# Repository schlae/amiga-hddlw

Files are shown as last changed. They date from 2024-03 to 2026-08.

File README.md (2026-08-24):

# Herr Doktor Diskettenlaufwerk (Amiga-HDDLW)

Late-model Amiga computers use customized floppy drives (like the Chinon
FZ-357A) to be able to read and write high-density floppy disks
(colloquially known as 1.44MB floppies, although the Amiga can store 1.76MB
because it packs in four additional sectors per track.)

Why a customized floppy drive? The Amiga custom chip, Paula, only supports
the slower bit rate used by double-density floppy disks. Instead of spending
a bunch of money to change the Paula chip, Commodore engineers got a
customized floppy drive that spun the disk at half speed when it detected
a high-density floppy disk.

In the 1990s, some 3rd party vendors released Amiga compatible floppy drives.
One such design is the AMTRADE "The Real HD-Drive" A357. It uses a modified
Sony MPF920-E or a TEAC FD-235HF (both fairly common) along with a small
adapter circuit board containing a 16V8 PAL.

I've done a bit of reverse engineering to understand how the A357 works,
and I've been able to build a functional replica. It's not an exact copy
because the original PAL is locked. I'm calling it the Herr Doktor
Diskettenlaufwerk, or HDDLW.

*Please note that I have not fabbed out this design yet, and although the
design is tested and expected to work, go forward at your own risk.*

## Fabrication

The board is a simple 2-layer affair with a small handful of parts. The
dimensions are 93.5mm x 20.3mm (3.68" x 0.8").

[Schematic](https://github.com/schlae/amiga-hddlw/blob/main/amiga-hddlw.pdf)

[Bill of Materials](https://github.com/schlae/amiga-hddlw/blob/main/amiga-hddlw.csv)

[Fab Package](https://github.com/schlae/amiga-hddlw/blob/main/fab/amiga-hddlw_rev1.zip)

Install a 20-pin DIP socket in position U1 just in case you have trouble
programming the PAL. All parts, with the exception of J2, J5, and J6, should
be installed on the top side of the board.

J4 should be a Molex 4-pin header with a key. In a pinch, you can sub it out
with a standard 4-pin header but it will be very easy to connect the cable
backwards, which will put 12V on the drive's 5V rail, destroying everything!

Install **either** J5 **or** J6 depending on the drive you plan to use. If you
install both, J5 will interfere with the drive select jumpers on the Sony
drive and potentially damage them.

Jumper J3 should be set to 1 for DF0 and 2 for DF1. Position 3 has not been
tested yet but may work.

## Rework

You will (most likely) need to add a bodge resistor to the design for it to
operate properly on many drives. This is because the pullup on the INDEX line
on the drive itself is weak or nonexistent. Connect a 10K ohm resistor from
pin 7 of the PAL to pin 20 of the PAL.

(Bottom view of the board)
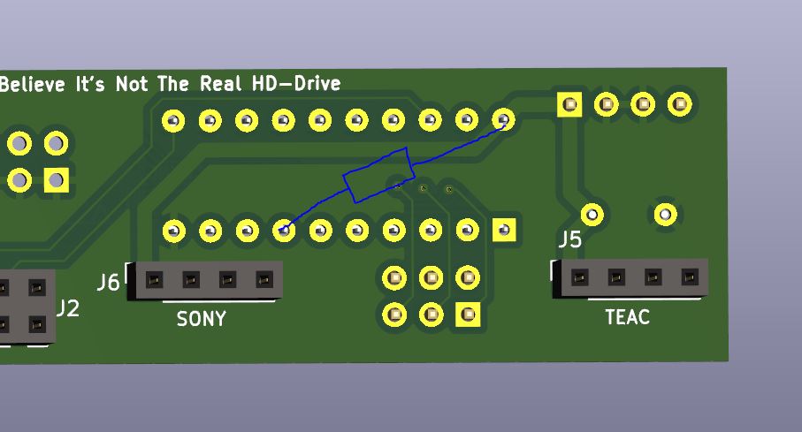
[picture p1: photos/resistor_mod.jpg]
Reverse view of the board showing resistor


## PAL programming

See the [source file](https://github.com/schlae/amiga-hddlw/blob/main/pal/amiga-hddlw.pld).

The logic equations are assembled using [galette](https://github.com/simon-frankau/galette)
and can be burned to the PAL using a number of different tools. I use the
TL-866 with the [minipro](https://gitlab.com/DavidGriffith/minipro) tool under
Linux, along with the ATF16V8B. The speed grade is not critical.

## Drive modifications

The HDDLW has been tested with the two floppy drives below. It may be possible
to use it with other drives, but you will need to investigate to figure out
the clock connection that sets the motor RPM. You will also need to figure
out how to get the high density select signal onto pin 4 of the drive.

### Sony MPF920-E

Perform the following changes

* Install JC40 (a zero ohm resistor or wire jumper), which is connected to pin
4 of the floppy connector and provides the high-density sense signal. See the
green circle in the image below.
* Cut the trace between pin 38 of IC1 and pin 16 of IC2. This is the motor
driver clock. This is indicated by the diagonal arrow in the image below.
* Connect a wire from pin 38 of IC1 to pin 14 of the floppy connector (blue
wire in the image)
* Connect a wire from pin 16 of IC2 to pin 6 of the floppy connector (red
wire in the image)
* (Optional) This drive *may* have issues regulating the motor speed at lower RPMs. You can try changing resistor R21 (located next to IC2) from 100K to a 68K resistor.

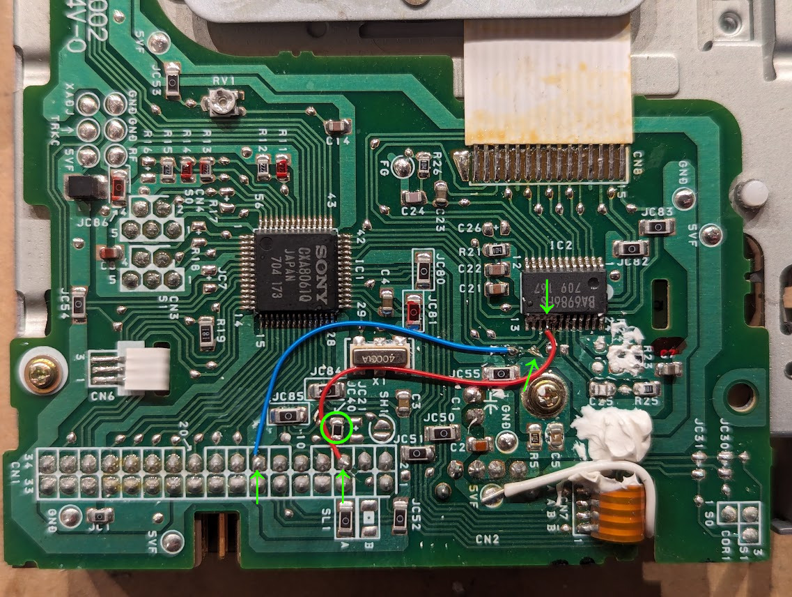
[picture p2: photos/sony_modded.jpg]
Modifications on the Sony MPF920-E


### TEAC FD-235HF

Perform the following changes

* Install S5 (a zero ohm resistor or wire jumper), which is connected to pin 4
of the floppy connector and provides the high-density sense signal (circled in
the image)
* Remove 1K resistor R9 (which may be named differently on different board
revs, but one end is always tied to pin 4 of J5; pointed to by the green
arrow)
* Connect a wire from U1 pin 48 to pin 14 of the floppy connector
* Connect a wire from J5 pin 4 to pin 6 of the floppy connector

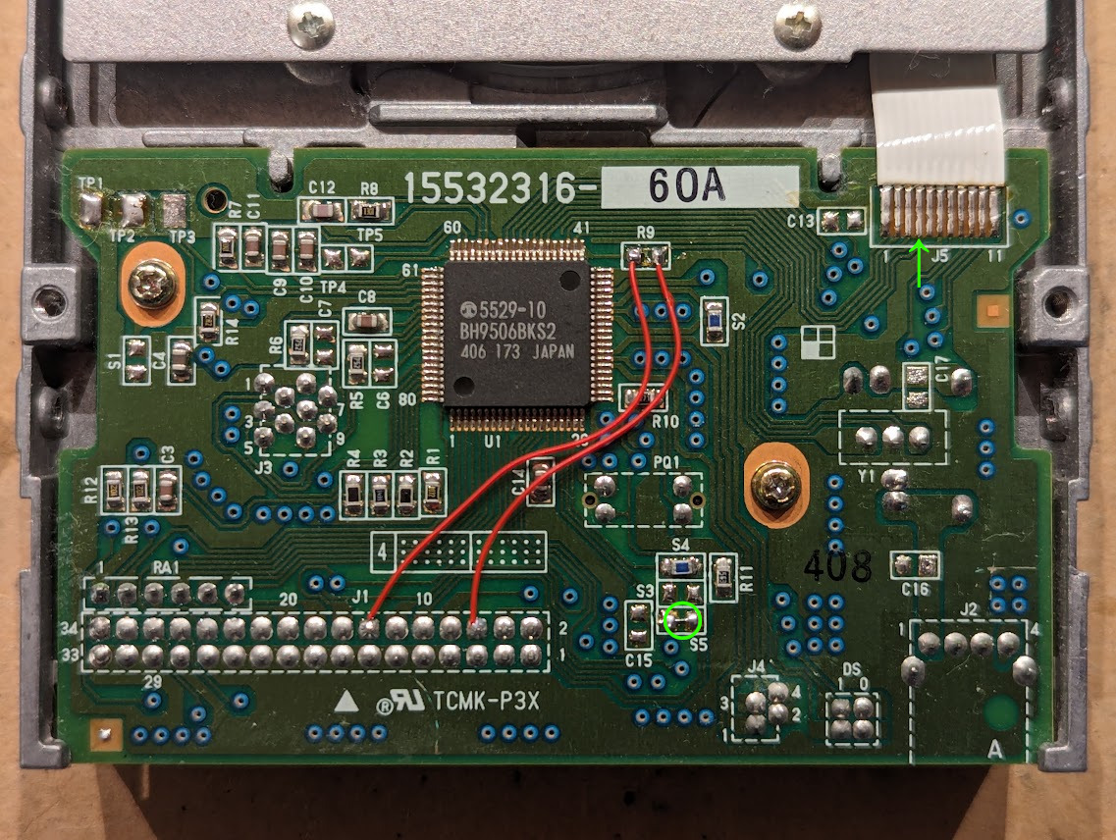
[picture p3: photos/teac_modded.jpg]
Modifications on the TEAC FD-235HF


TEAC used several different board versions, so your board may not look exactly
alike. The example below uses R12 instead of R9, and S5 has been moved although
it retains the same designator.

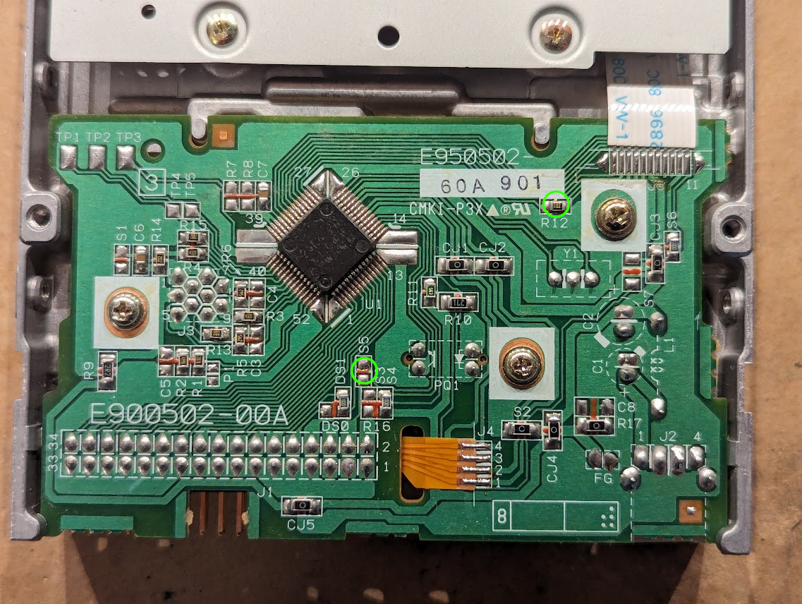
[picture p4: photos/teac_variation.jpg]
Alternate TEAC board


Another alternative board uses R12 (as above) but uses S6 instead of S5.

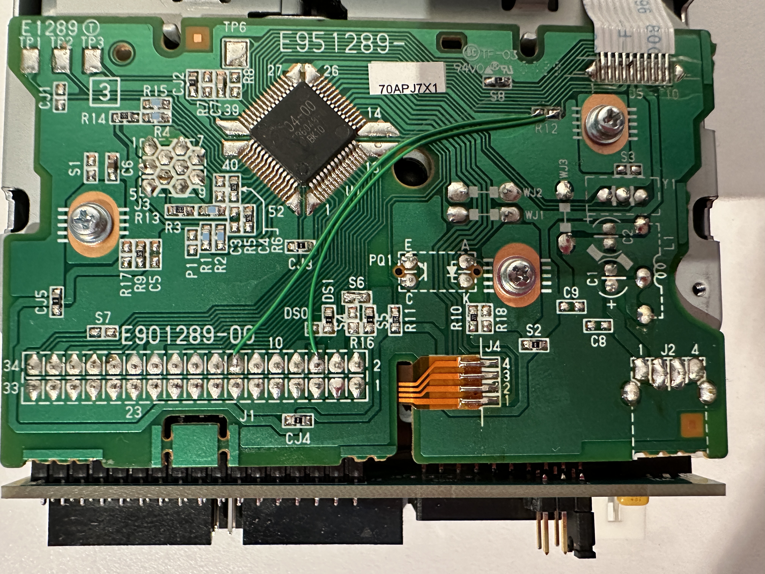
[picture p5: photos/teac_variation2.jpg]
Second alternate TEAC board


## Functional Explanation

The drive modifications intercept the clock signal that goes between the
floppy drive's main control IC and the motor controller, bringing them out
to two unused pins on the floppy connector. They also enable the undocumented
feature that provides a high-density detect output on pin 4.

The PAL checks for high density disks by looking at pin 4. If a high density
disk is inserted, the PAL

* Divides the motor clock by 2 to slow the RPM from 300 to 150rpm
* Returns the drive ID pattern `10101010...` to the Amiga to let it know that
this is a high-density drive/disk.

If a double-density disk is inserted, the PAL

* Passes the motor clock signal through unchanged so the disk spins at 300rpm
* Returns the drive ID pattern `11111111...`, a double-density drive/disk

And that's about it.

## Troubleshooting

Some folks have issues where high density disks will sometimes read but will not format correctly. This can be caused by the motor speed not regulating well at the lower RPM. On the Sony drive, you can replace R21 with a 68K resistor. The TEAC drives may have similar problems but I haven't figured out a rework for them.

## License
This work is licensed under a Creative Commons Attribution-ShareAlike 4.0
International License. See [https://creativecommons.org/licenses/by-sa/4.0/](https://creativecommons.org/licenses/by-sa/4.0/).

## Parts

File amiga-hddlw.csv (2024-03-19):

Item | Qty | Reference(s) | Value | Mouser
1 | 1 | C1 | 0.1uF | 594-K104K10X7RF53H5 or equiv
2 | 1 | J1 | Amiga Side | 737-BHR-34-VUA or equiv
3 | 1 | J2 | Floppy Drive | 517-929975-01-17-RK or equiv
4 | 1 | J3 | SEL | (Just use generic breakaway header)
5 | 1 | J4 | Power In | 571-1718254
6 | 1 | J5 or J6 | Power Out | 571-5-146763-6 or equiv
7 | 1 | U1 | GAL16V8 | 556-AF16V8B15PU

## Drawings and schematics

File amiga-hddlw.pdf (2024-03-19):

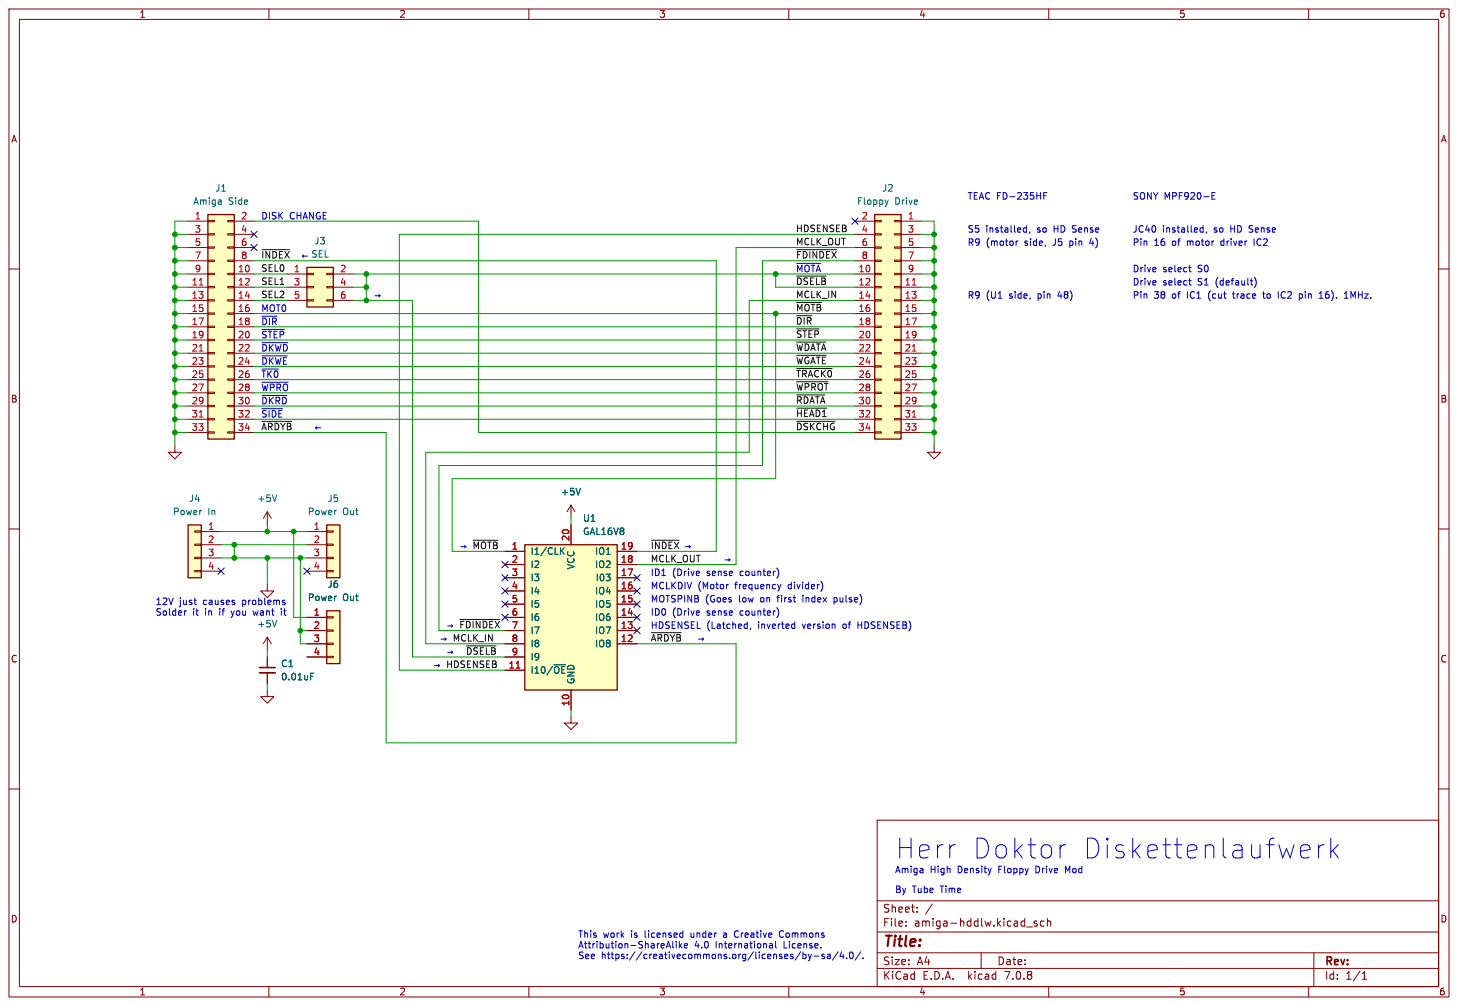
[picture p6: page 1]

Amiga High Density Floppy Drive Mod
By Tube Time
Id: 1/1 Title: File: amiga-hddlw.kicad_sch Sheet: /

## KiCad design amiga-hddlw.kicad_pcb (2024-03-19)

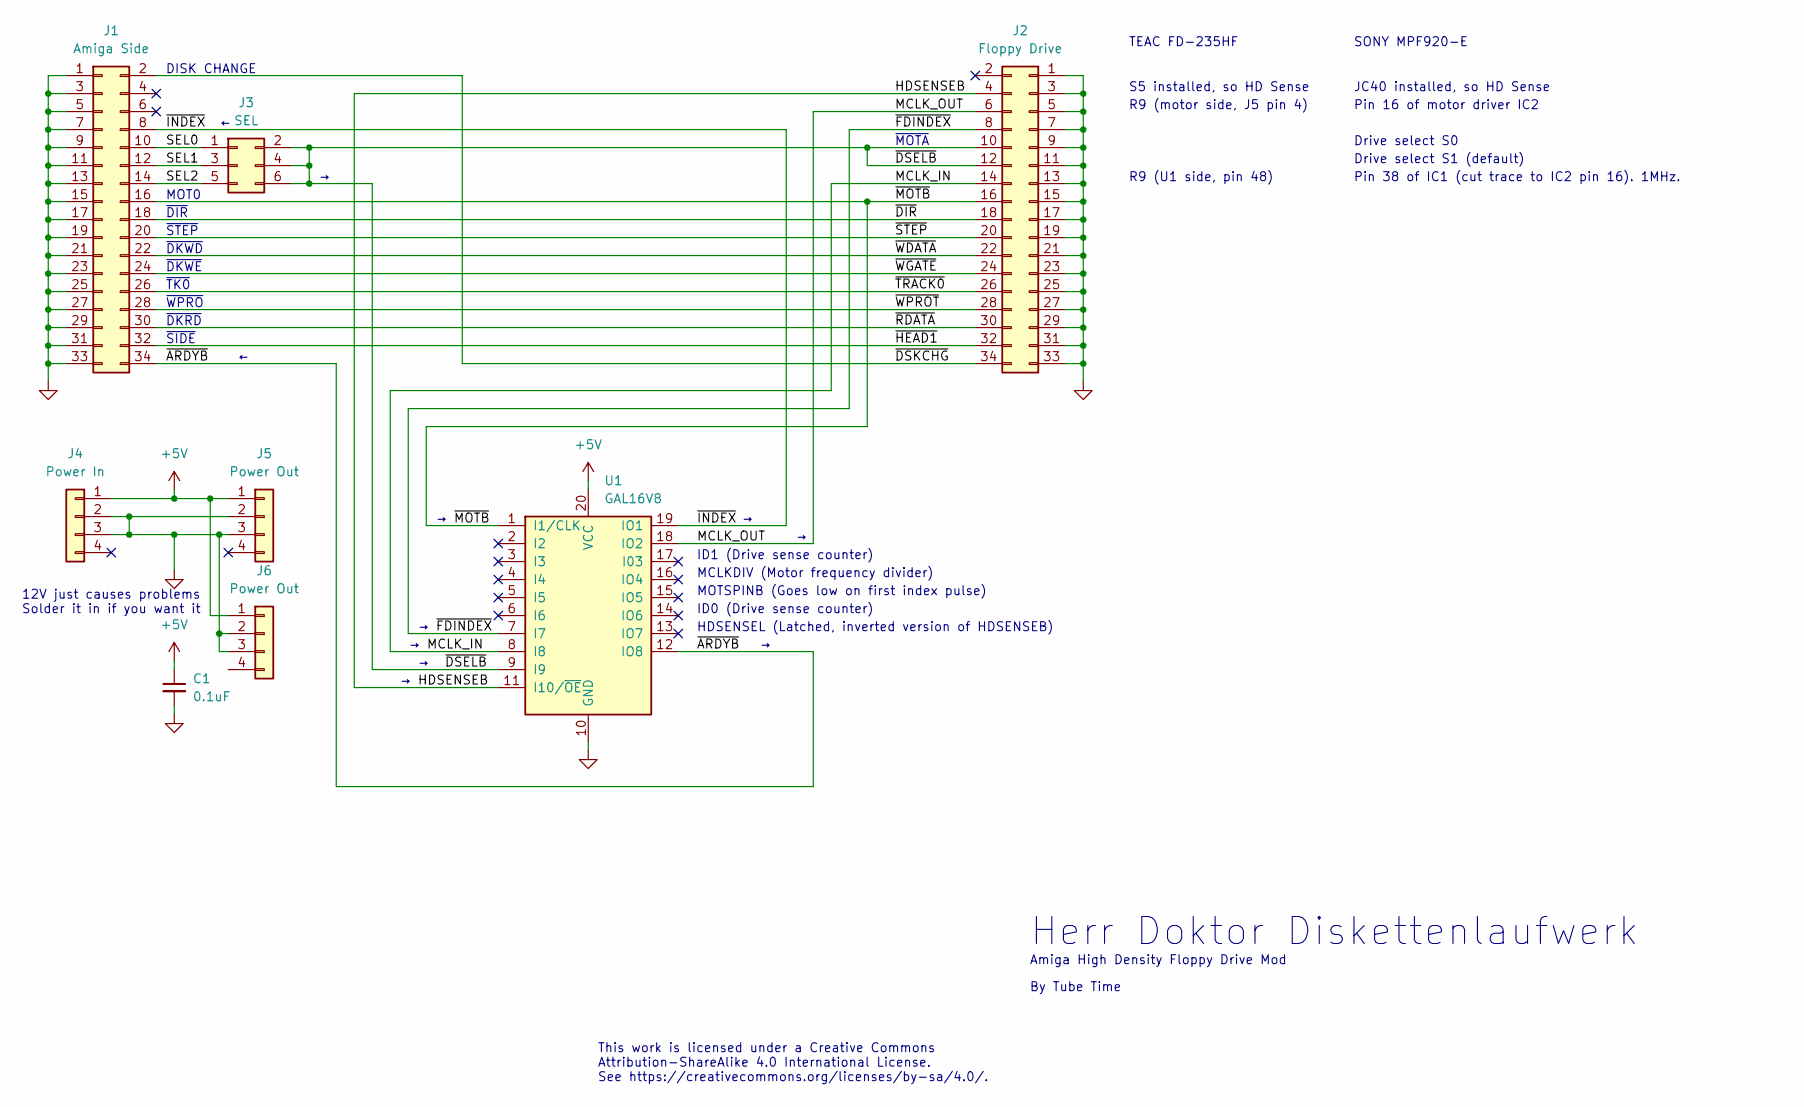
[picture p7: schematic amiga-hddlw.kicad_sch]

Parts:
C1: 0.1uF; CAPAC200; Mouser 594-K104K10X7RF53H5 or equiv
J1: Amiga Side; HEADER_2x17_254_SHROUDED; Mouser 737-BHR-34-VUA or equiv
J2: Floppy Drive; PinSocket_2x17_P2.54mm_Vertical; Mouser 517-929975-01-17-RK or equiv
J3: SEL; PinHeader_2x03_P2.54mm_Vertical; Mouser (Just use generic breakaway header)
J4: Power In; PinHeader_1x04_P2.54mm_Vertical; Mouser 571-1718254
J5: Power Out; PinSocket_1x04_P2.54mm_Vertical; Mouser 571-5-146763-6 or equiv
J6: Power Out; PinSocket_1x04_P2.54mm_Vertical
U1: GAL16V8; DIP254P762X635-20; Mouser 556-AF16V8B15PU

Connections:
+5V: C1.1, J4.1, J5.1, J6.1, U1.20 (VCC)
/HDSENSEB: J2.4, U1.11 (I10/~OE)
/MCLK_IN: J2.14, U1.8 (I8)
/MCLK_OUT: J2.6, U1.18 (IO2)
/SEL0: J1.10, J3.1
/SEL1: J1.12, J3.3
/SEL2: J1.14, J3.5
/~ARDYB: J1.34, U1.12 (IO8)
/~DIR: J1.18, J2.18
/~DSELB: J2.10, J2.12, J3.2, J3.4, J3.6, U1.9 (I9)
/~DSKCHG: J1.2, J2.34
/~FDINDEX: J2.8, U1.7 (I7)
/~HEAD1: J1.32, J2.32
/~INDEX: J1.8, U1.19 (IO1)
/~MOTB: J1.16, J2.16, U1.1 (I1/CLK)
/~RDATA: J1.30, J2.30
/~STEP: J1.20, J2.20
/~TRACK0: J1.26, J2.26
/~WDATA: J1.22, J2.22
/~WGATE: J1.24, J2.24
/~WPROT: J1.28, J2.28
GND: C1.2, J1.1, J1.3, J1.5, J1.7, J1.9, J1.11, J1.13, J1.15, J1.17, J1.19, J1.21, J1.23, J1.25, J1.27, J1.29, J1.31, J1.33, J2.1, J2.3, J2.5, J2.7, J2.9, J2.11, J2.13, J2.15, J2.17, J2.19, J2.21, J2.23, J2.25, J2.27, J2.29, J2.31, J2.33, J4.2, J4.3, J5.2, J5.3, J6.2, J6.3, U1.10 (GND)

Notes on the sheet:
DISK CHANGE
~{WPRO}
MOTSPINB (Goes low on first index pulse)
S5 installed, so HD Sense
By Tube Time
MCLKDIV (Motor frequency divider)
HDSENSEL (Latched, inverted version of HDSENSEB)
~{DKWE}
Pin 38 of IC1 (cut trace to IC2 pin 16). 1MHz.
~{STEP}
Amiga High Density Floppy Drive Mod
JC40 installed, so HD Sense
SONY MPF920-E
~{TK0}
Herr Doktor Diskettenlaufwerk
~{DIR}
Drive select S1 (default)
ID0 (Drive sense counter)
R9 (motor side, J5 pin 4)
~{MOTA}
12V just causes problems Solder it in if you want it
Pin 16 of motor driver IC2
~{DKWD}
ID1 (Drive sense counter)
~{DKRD}
Drive select S0
R9 (U1 side, pin 48)
MOT0
This work is licensed under a Creative Commons Attribution-ShareAlike 4.0 International License. See https://creativecommons.org/licenses/by-sa/4.0/.
~{SIDE}
TEAC FD-235HF

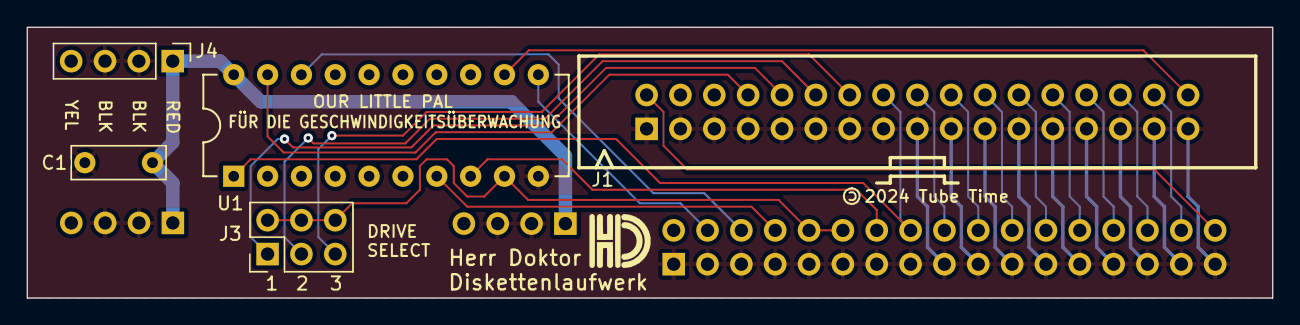
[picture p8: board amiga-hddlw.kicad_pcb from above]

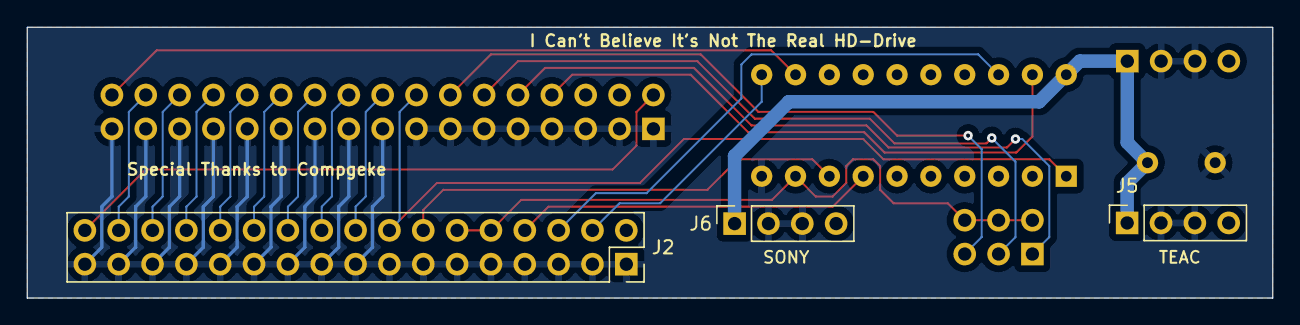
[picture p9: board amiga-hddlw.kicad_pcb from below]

Board: 2 copper layers, 93.5 x 20.3 mm, 8 parts (3 on the bottom side), 22 nets.

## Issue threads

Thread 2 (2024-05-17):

Unable to read/write hd disks

apolkosnik, 2024-05-17:
It looks like the drivespeed (from pc2amiga package on aminet)reports 145 rpm. I'm using the alternative TEACs, but HD doesn't seem to be working properly. I'm wondering if it's due to building the .jed on windows.

schlae, 2024-05-17:
could be. what PAL are you using?

apolkosnik, 2024-05-17:
ATF16V8B-15PU from mouser

schlae, 2024-05-17:
How are you building the JEDEC file? Can you try using the prebuilt one I just added to the repo?

apolkosnik, 2024-05-18:
I've used galette, and just did a compare and it's same as the one in the repo

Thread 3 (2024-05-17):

Another version of the TEAC FD-235HF to share with different component references

ljmarent, 2024-05-17:
TEAC FD-235HF C829

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

Multi-meter identifies R12 and S6 are the target parts on this version of the PCB

schlae, 2024-05-17:
Thank you, can you provide a top-down photo of the PCB so I can include it?

ljmarent, 2024-05-17:
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

schlae, 2024-05-18:
Thanks, it has been added.

Closed 2024-05-18.

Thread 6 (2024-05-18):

Unable to format 1.76MB disks successfully

ljmarent, 2024-05-18:
I don't have a collection of Amiga software on floppy to test with.
So the first thing I've trying to do is format DD and HD disks

Format of DD disk successful
Format of HD disk, detects 1.76MB disk, not successful in completing format.

Detection:
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

Failure:
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

It fails on different cylinder numbers each time.. usually 0, 1, 2... but I've gotten as far as 31

Alternative Failure:
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

I've also run the drive speed program, like the other active read\write issue.
with DD disks it shows 600RPM Average
with HD disks it shows 300RPM Average

Utility location:
DRIVESPEED found int he LHA located at
https://aminet.net/package/docs/hard/PCFloppy2Amiga

Usage:
"DRIVESPEED 0" where 0 is my track device number

apolkosnik, 2024-05-18:
I can replicate the issues with formatting on the 3 TEAC first alternative drive models that I've modified.

ljmarent, 2024-05-18:
I took the top lid off my TEAC drive and can see it struggling to format .. it stalls on a cylinder, tries it a couple times, then gives up.

ljmarent, 2024-05-19:
#FDINDEX[8] from the TEAC drive appears to be stuck at ground...
I'm going to try pulling this signal up
To see if it's maybe an open-collector output

ljmarent, 2024-05-19:
#FDINDEX[8] is giving me a 2.5HZ pulse with a HD disk
#FDINDEX[8] is giving me a 5.011Hz pulse with a DD disk

apolkosnik, 2024-05-20:
"The INDEX signal is a short pulse which the drive delivers once per revolution of the diskette, between the start and end of a track."
So that signal is ok, since the hd floppies spin at half the regular speed.

schlae, 2024-05-20:
hmm i'm wondering if i missed a drive modification. maybe something to tweak the read channel to work better at the lower speed.

apolkosnik, 2024-08-03:
I've tried a Sony drive, and it works great in DD, but has issues in HD mode

schlae, 2024-08-03:
can you capture some photos of the floppy drive's circuit board? also the *exact* manufacturer part number of the PAL you are using.

TommyEriksen, 2024-08-12:
I converted a Sony drive. Played with it on my A1000 with a Rejuvenator board. I had an old version of EMU68 on it with kickstart 3.2.1 and could not format HD floppies. Upgraded to latest release of EMU68, same kickstart/workbench combo and then I could format HD floppies without any problems. Not sure if this somehow can be transferred to a real CPU, but to me it doesnt look like it is the drive that has the problem.

bartekre, 2024-12-11:
I encountered the same issue and came across [a similar project on EAB](https://eab.abime.net/showthread.php?t=114674) from about a year ago. It seems that, for some drives, the motor becomes unstable at lower RPMs. According to the documentation, in such cases, the 100K resistor connected to pin 18 of the BA6986FS chip should be replaced with one in the 56K–68K range. In my case, with the MPF920-E drive, I replaced R21 with a 68K resistor. After doing so, I was able to format 1.76MB floppies without any issues!

I believe a similar modification may be necessary for Teac drives, though I wasn't able to find any specific information on that.
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

schlae, 2024-12-12:
Thanks, I've updated the documentation. I'm leaving the bug open since I don't know the rework for the TEAC drives.

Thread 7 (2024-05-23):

Not all Teac FD235HFs are created equal (FD235HF-4240 is not suitable for this modification)

rhalkyard, 2024-05-23:
I'm working on applying the same principles as the HDDLW to retrofit high-density support to old Acorn Archimedes systems, and while experimenting with drives in my junk drawer, I came across a variant of the Teac FD235HF that does not appear to be suitable for this modification: the FD235HF-4240 has a 10-pin (rather than 11-pin) connector to the motor board, and the motor controller's OSC1 and OSC2 pins are connected to a crystal on the motor board (Y61 in my example), rather than having OSC1 driven by a clock from the main IC.

Aside from the -4240 model suffix, the other distinguishing feature of this variant is an unusual blue-coloured external layer on the main PCB. Never seen that before.

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

While I'm here, I might as well also add that the Sony MP-F17W doesn't seem to take well to this modification either. Though it has a convenient 0-ohm resistor that makes it easy to interpose the motor clock, the motor has fewer slots than most others I've seen, and at half speed, you get visible torque pulsations (and some pretty horrible noises). No bueno.

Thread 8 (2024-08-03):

Power connector alignment

gavin-101, 2024-08-03:
For the Sony drives, the power connector is high on the pcb. It is needing alignment to the bottom of the pcb to be a simple direct plug-in solution. Slight lifting of the floppy drive power connector and lowering of the pcb power connector by bending the connectors pins before soldering in place is necessary with the current design.

schlae, 2024-08-03:
how far off is it? can you get a measurement?

gavin-101, 2024-08-05:
Hi, it's not much. I'd estimate 1.5mm to 2mm maximum lower. I've checked a few online images and I think the easiest way to define it is to align the pins centrally to the floppy connector. Sony seem to have used a few different power connectors but are close tolerances. 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

gavin-101, 2024-08-05:
Second image.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

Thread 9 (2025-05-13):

Is the original Amtrade Adapter compatible to these drive mods?

Lalarian, 2025-05-13:
Hello!

I have an original 'The real HD-Fix" adapter.

I modded two drives.
One TEAC HD235 and one Sony 920-E.

But:
Both are working perfectly as DD drives, but none is working in HD mode.
They both can neither successfully write a HD disk not read a HD disk written by another drive.

The RPM of the TEAC is a bit low and I can't do a thing about it.
The RPM of the Sony drive is near perfect, in DD mode (period 200) as well as in HD mode (period between 400.1 and 398.7).
So I don't think the resistor mod is needed.

What could be the reason that both drives work as DD but not as HD?
Is there possibly a little difference between hddlw and 'The real HD-Fix'?

Many thanks for help! :)

schlae, 2025-05-14:
how are you monitoring the RPM? i have a feeling it's not stable, and it would be worthwhile to try the resistor mod. another possibility is that the GAL you're using is not fully compatible with the original. do you have the full part number (including all suffixes, manufacturer info, etc)?

Lalarian, 2025-05-14:
Hi Schlae!

For the RPM I am just watching the period time in Amiga Testkit for half a minute and remember min and max. On the one hand I thought about doing the resistor mod multiple times, on the other hand: If I have ever seen stable RPM, then it's this drive. Probably I will still try the mod if there's no other choice left to do ..

My GAL is an original one, as I did not build this adapter myself. It's the original that I bought in the 90s.
But: After working at this part for some hours I think I remember that the drive that I bought back then (which included the Amtrade adapter) never worked correctly even new. Probably this also is why I had the sole adapter in a box until now. (Not too sure about all of this, as it have been some years :) )

Now I think I now possibly found part of the the issue (yet not the reason..) : While slowing the speed down correctly with a HD disk inside, the floppy drive with adapter does not identiy as HD. Amiga Testkit always shows DD, even with HD disk inside an after rebooting. Is this normal behaviour? Would this behaviour stem from the adapter or thje drive itself?

I  read someone saying that the reason might be me using an external floppy case instead of attaching the drive internally, because the case's logic IC might interfere with the ready signal - but I just measured my external case and saw that the ready signal from the drive's  (or better: the Amtrade adapter's) PIN34 is directly passed through to pin1 of the external connector, so I think this probably is not the reason.

What else might be the reason?
Is it possibnly a broken GAL?
Or does the drive not correctly give out ther HD signal to the Amtrade adapter?
Or did this original Amtrade adapter maybe use another pin than pin4 for inputting from the drive's HD signal?

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

Lalarian, 2025-05-20:
OK:
The reason actually is the external drive. It seems the HD signal gets eaten in the ICs from the case's PCB. Sadly I don't know how to mod this to a working condition.
Initial questions is answered.

Closed 2025-05-20.
